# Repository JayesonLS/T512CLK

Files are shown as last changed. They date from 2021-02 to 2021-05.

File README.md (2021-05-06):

Schematics for the ATD T512CLK-A1 derived from Rob Krenicki's board layout
==========================================================================

There may be errors. That said, I found none in Rob Krenicki's work. KiCad's ERC and DRC checks likely caught all important errors in my work.

Do not produce the PCB layout from this KiCad project. Placing of standard KiCad parts onto the board has resulted in insufficient track spacing for production. If you wish to make a board, use Rob Krenicki's gerbers.

**Data point of note:** the required clock chip appears to be a DS1216B or DS1216C. I have tested a DS1216C successfully. I believe either variant will work given that no chip will be fitted into the DS1216. Note that this clock chip is not the more typical DS1216E SmartWatch chip for which there are reproductions. I have designed a replacement here: https://github.com/JayesonLS/SmartWatchRedux . Alternatively, used DS1216B or DS1216C's are still readily available from eBay, etc. They likely have dead batteries and an external replacement battery can be retrofitted with some work. Google "DS1216 battery replacement".

Software for the ATD-20 (or DS1216-C) clock fitted to a T512CLK-A1 is available from here: http://www.minuszerodegrees.net/rtc/rtc.htm . This software seems to correctly support current dates.

More information on the T512CLK is available from Rob Krenicki's project: https://github.com/rkrenicki/Tandy1000-DMA-Upgrade

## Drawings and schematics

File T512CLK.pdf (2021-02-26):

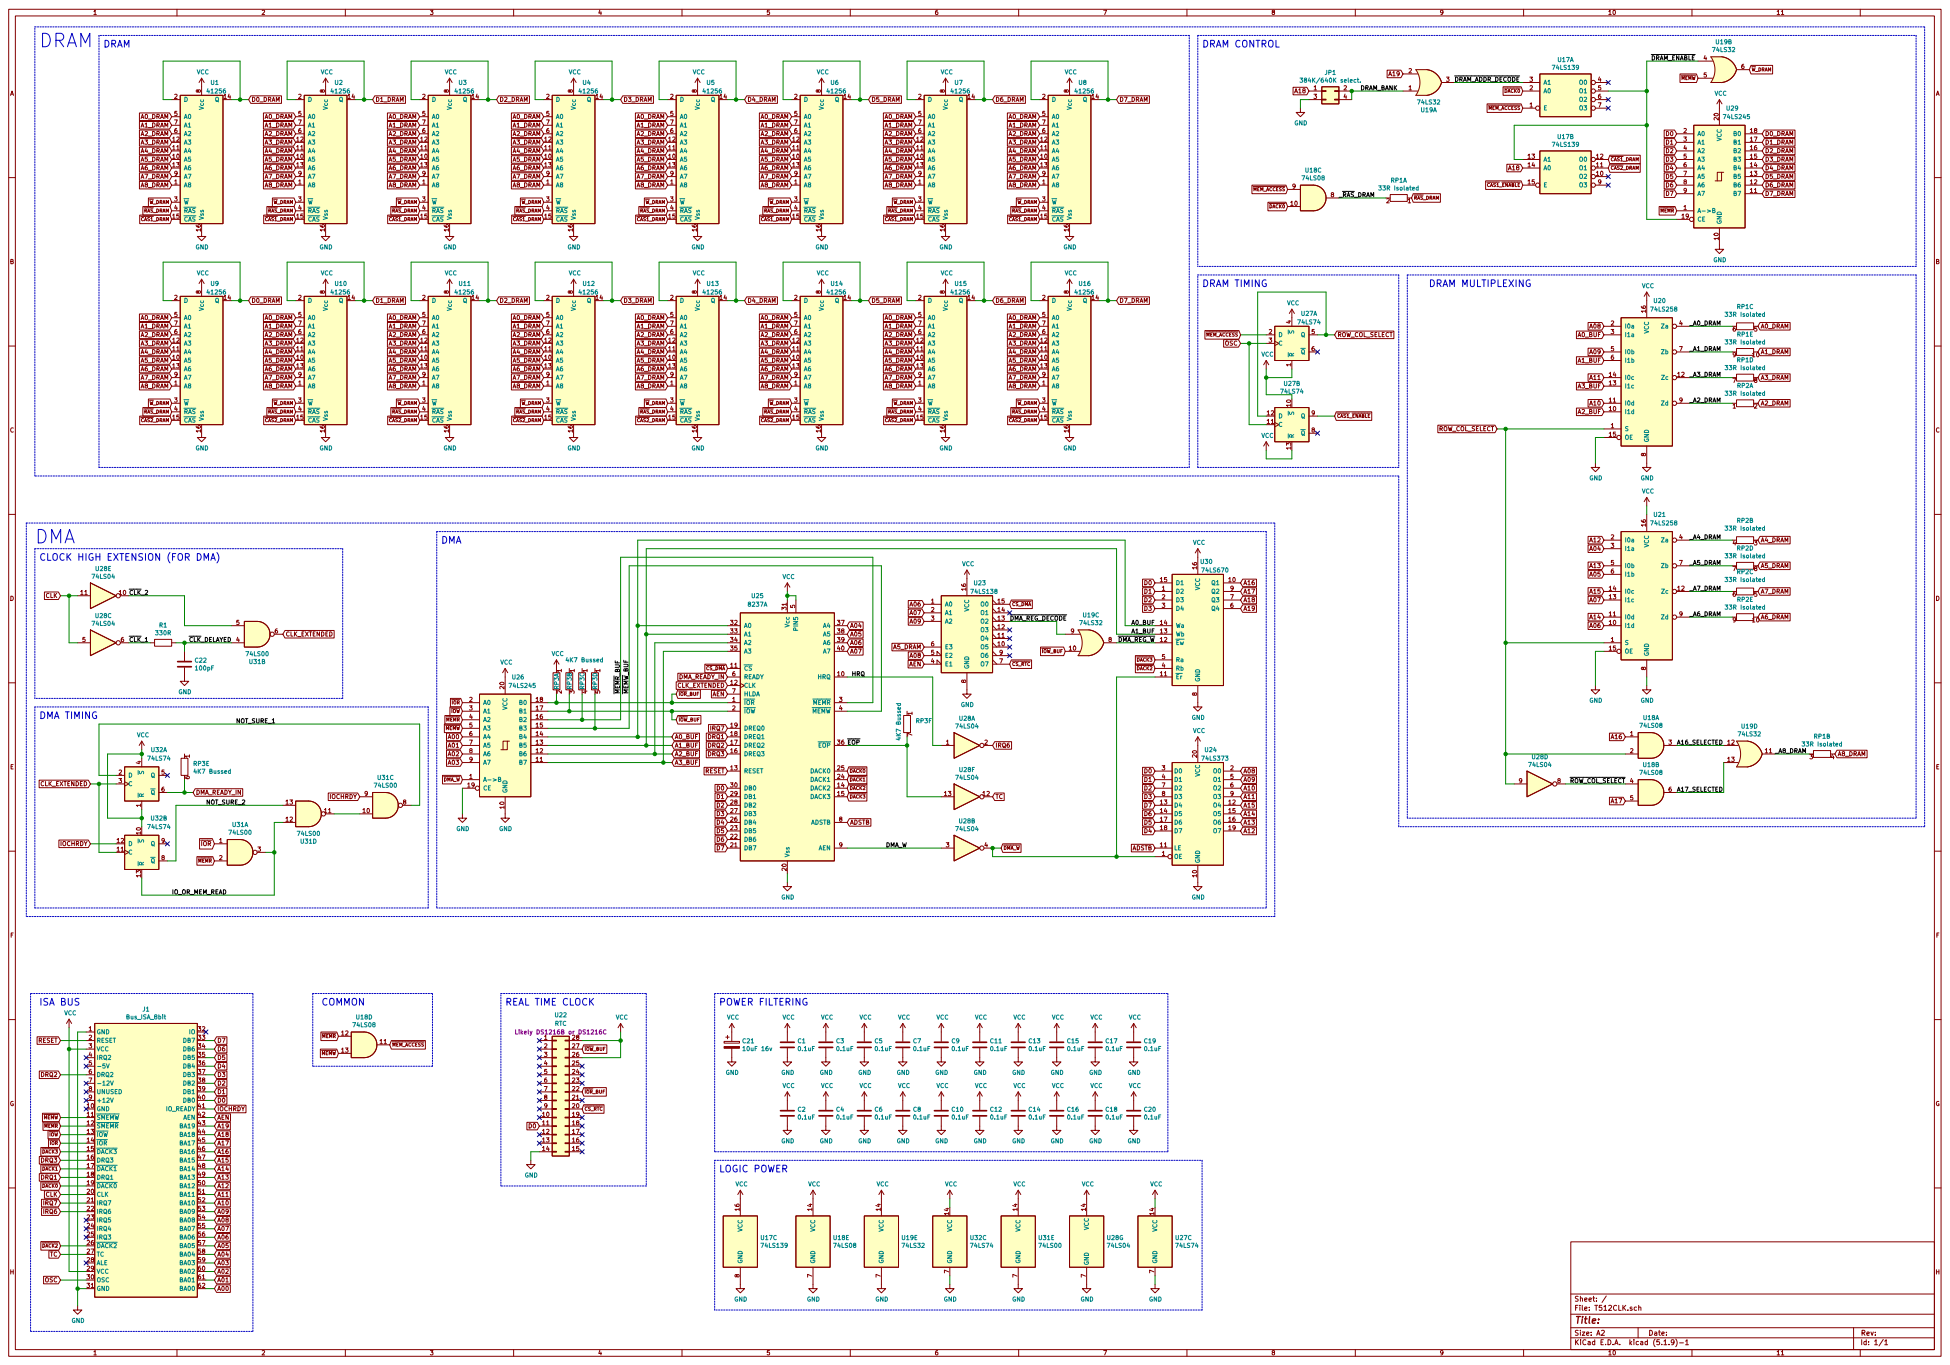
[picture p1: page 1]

CLOCK HIGH EXTENSION (FOR DMA)

5 READY 6 HLDA 7 ADSTB 8 AEN 9 U25

0.1uF GND
Id: 1/1 Title: File: T512CLK.sch Sheet: / VCC

74LS32 VCC GND VCC 14 GND

74LS74 VCC GND VCC 14 GND

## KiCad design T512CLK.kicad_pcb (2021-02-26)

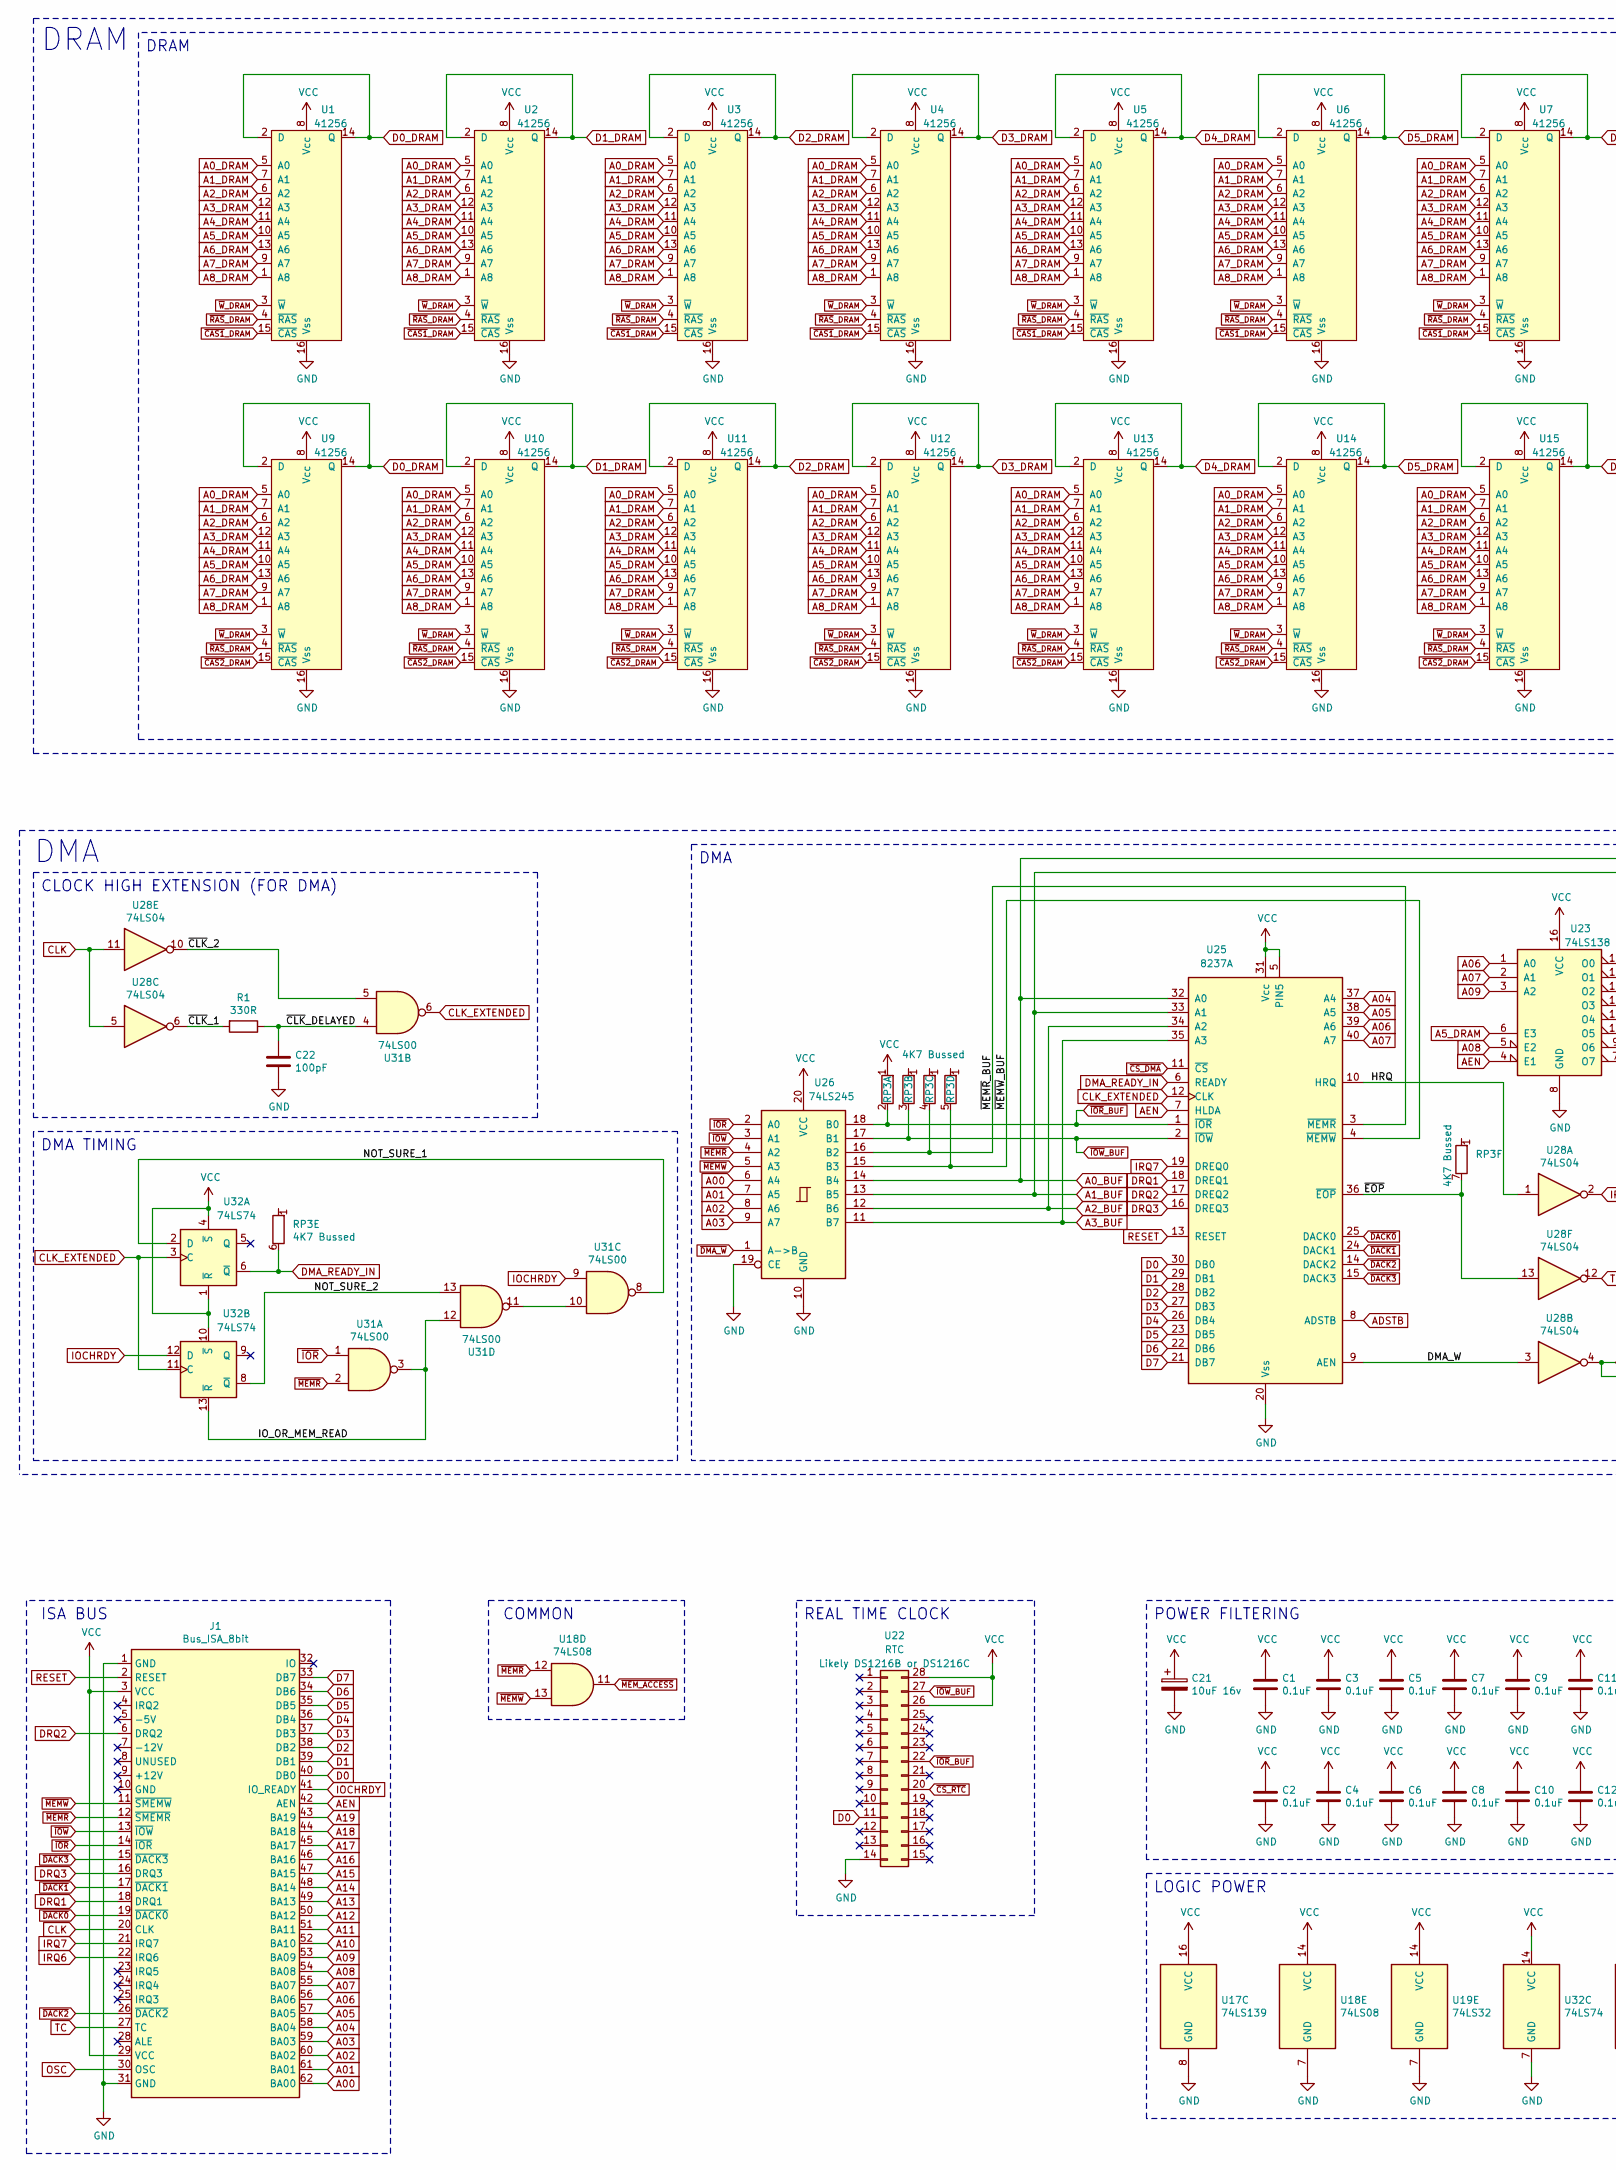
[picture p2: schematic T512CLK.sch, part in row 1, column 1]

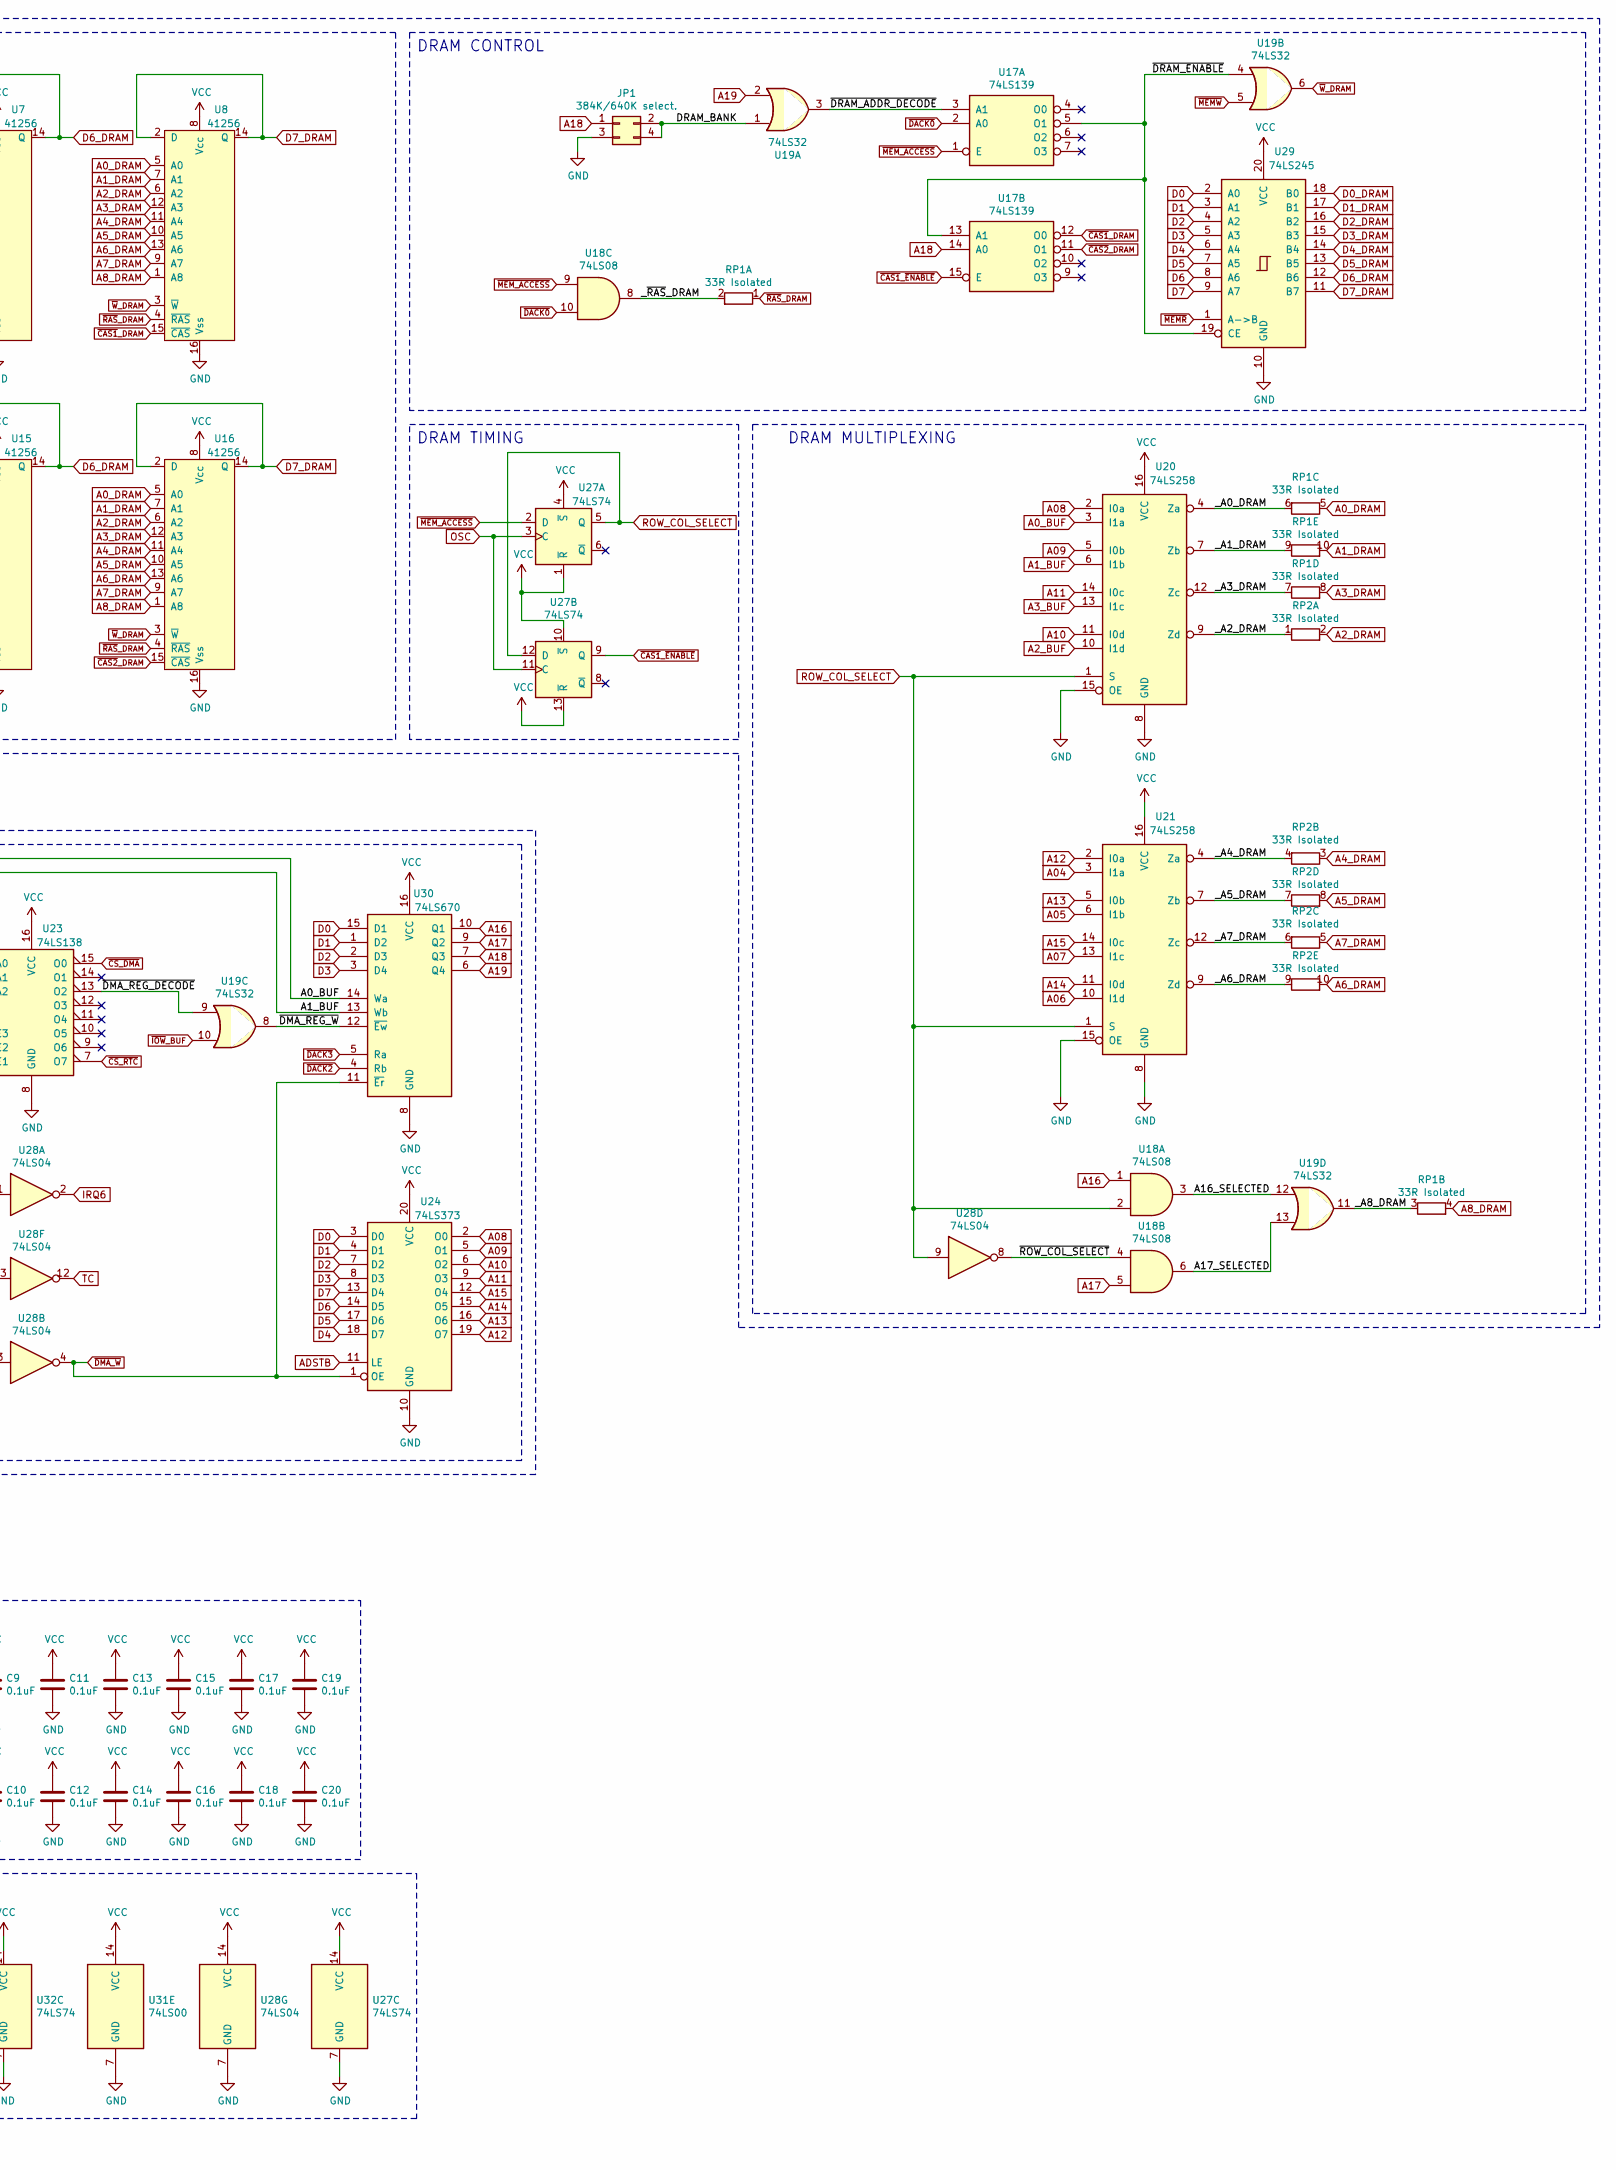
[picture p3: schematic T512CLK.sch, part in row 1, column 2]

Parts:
C1, C2, C3, C4, C5, C6, C7, C8, C9, C10, C11, C12, C13, C14, C15, C16, C17, C18, C19, C20: 0.1uF; C_Ceramic
C21: 10uF 16v; CP_Radial_Tantal_D5.0mm_P2.50mm
C22: 100pF; C_Ceramic
J1: Bus_ISA_8bit; BUS_AT
JP1: 384K/640K select.; PinHeader_2x02_P2.54mm_Vertical
R1: 330R; R_Axial_DIN0309_L9.0mm_D3.2mm_P12.70mm_Horizontal
RP1, RP2: 33R Isolated; R_Array_SIP10
RP3: 4K7 Bussed; R_Array_SIP8
U1, U2, U3, U4, U5, U6, U7, U8, U9, U10, U11, U12, U13, U14, U15, U16: 41256; DIP-16_W7.62mm
U17: 74LS139; DIP-16_W7.62mm
U18: 74LS08; DIP-14_W7.62mm
U19: 74LS32; DIP-14_W7.62mm
U20, U21: 74LS258; DIP-16_W7.62mm
U22: RTC; DIP-28_W15.24mm
U23: 74LS138; DIP-16_W7.62mm
U24: 74LS373; DIP-20_W7.62mm
U25: 8237A; DIP-40_W15.24mm
U26, U29: 74LS245; DIP-20_W7.62mm
U27, U32: 74LS74; DIP-14_W7.62mm
U28: 74LS04; DIP-14_W7.62mm
U30: 74LS670; DIP-16_W7.62mm
U31: 74LS00; DIP-14_W7.62mm

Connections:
/A16_SELECTED: U18.3, U19.12
/A17_SELECTED: U18.6, U19.13
/DMA_W: U25.9 (AEN), U28.3
/DRAM_BANK: JP1.2, JP1.4, U19.1
/HRQ: U25.10 (HRQ), U28.1
/IO_OR_MEM_READ: U31.3, U31.12, U32.13 (~R)
/NOT_SURE_1: U31.8, U32.2 (D)
/NOT_SURE_2: U31.13, U32.8 (~Q)
/_A0_DRAM: RP1.6 (R3.2), U20.4 (Za)
/_A1_DRAM: RP1.9 (R5.1), U20.7 (Zb)
/_A2_DRAM: RP2.1 (R1.1), U20.9 (Zd)
/_A3_DRAM: RP1.7 (R4.1), U20.12 (Zc)
/_A4_DRAM: RP2.4 (R2.2), U21.4 (Za)
/_A5_DRAM: RP2.7 (R4.1), U21.7 (Zb)
/_A6_DRAM: RP2.9 (R5.1), U21.9 (Zd)
/_A7_DRAM: RP2.6 (R3.2), U21.12 (Zc)
/_A8_DRAM: RP1.3 (R2.1), U19.11
/_~RAS~_DRAM: RP1.2 (R1.2), U18.8
/~CLK~_1: R1.2, U28.6
/~CLK~_2: U28.10, U31.5
/~CLK~_DELAYED: C22.1, R1.1, U31.4
/~DMA_REG_DECODE: U19.9, U23.13 (O2)
/~DMA_REG_W: U19.8, U30.12 (~Ew)
/~DRAM_ADDR_DECODE: U17.3 (A1), U19.3
/~DRAM_ENABLE: U17.5 (O1), U17.13 (A1), U19.4, U29.19 (CE)
/~EOP: RP3.7 (R6.2), U25.36 (~EOP~), U28.13
/~MEMR~_BUF: RP3.4 (R3.2), U25.3 (~MEMR~), U26.16 (B2)
/~MEMW~_BUF: RP3.5 (R4.2), U25.4 (~MEMW~), U26.15 (B3)
/~ROW_COL_SELECT: U18.4, U28.8
A00: J1.62 (BA00), U26.6 (A4)
A0_BUF: U20.3 (I1a), U25.32 (A0), U26.14 (B4), U30.14 (Wa)
A0_DRAM: RP1.5 (R3.1), U1.5 (A0), U2.5 (A0), U3.5 (A0), U4.5 (A0), U5.5 (A0), U6.5 (A0), U7.5 (A0), U8.5 (A0), U9.5 (A0), U10.5 (A0), U11.5 (A0), U12.5 (A0), U13.5 (A0), U14.5 (A0), U15.5 (A0), U16.5 (A0)
A01: J1.61 (BA01), U26.7 (A5)
A1_BUF: U20.6 (I1b), U25.33 (A1), U26.13 (B5), U30.13 (Wb)
A1_DRAM: RP1.10 (R5.2), U1.7 (A1), U2.7 (A1), U3.7 (A1), U4.7 (A1), U5.7 (A1), U6.7 (A1), U7.7 (A1), U8.7 (A1), U9.7 (A1), U10.7 (A1), U11.7 (A1), U12.7 (A1), U13.7 (A1), U14.7 (A1), U15.7 (A1), U16.7 (A1)
A02: J1.60 (BA02), U26.8 (A6)
A2_BUF: U20.10 (I1d), U25.34 (A2), U26.12 (B6)
A2_DRAM: RP2.2 (R1.2), U1.6 (A2), U2.6 (A2), U3.6 (A2), U4.6 (A2), U5.6 (A2), U6.6 (A2), U7.6 (A2), U8.6 (A2), U9.6 (A2), U10.6 (A2), U11.6 (A2), U12.6 (A2), U13.6 (A2), U14.6 (A2), U15.6 (A2), U16.6 (A2)
A03: J1.59 (BA03), U26.9 (A7)
A3_BUF: U20.13 (I1c), U25.35 (A3), U26.11 (B7)
A3_DRAM: RP1.8 (R4.2), U1.12 (A3), U2.12 (A3), U3.12 (A3), U4.12 (A3), U5.12 (A3), U6.12 (A3), U7.12 (A3), U8.12 (A3), U9.12 (A3), U10.12 (A3), U11.12 (A3), U12.12 (A3), U13.12 (A3), U14.12 (A3), U15.12 (A3), U16.12 (A3)
A04: J1.58 (BA04), U21.3 (I1a), U25.37 (A4)
A4_DRAM: RP2.3 (R2.1), U1.11 (A4), U2.11 (A4), U3.11 (A4), U4.11 (A4), U5.11 (A4), U6.11 (A4), U7.11 (A4), U8.11 (A4), U9.11 (A4), U10.11 (A4), U11.11 (A4), U12.11 (A4), U13.11 (A4), U14.11 (A4), U15.11 (A4), U16.11 (A4)
A05: J1.57 (BA05), U21.6 (I1b), U25.38 (A5)
A5_DRAM: RP2.8 (R4.2), U1.10 (A5), U2.10 (A5), U3.10 (A5), U4.10 (A5), U5.10 (A5), U6.10 (A5), U7.10 (A5), U8.10 (A5), U9.10 (A5), U10.10 (A5), U11.10 (A5), U12.10 (A5), U13.10 (A5), U14.10 (A5), U15.10 (A5), U16.10 (A5), U23.6 (E3)
A06: J1.56 (BA06), U21.10 (I1d), U23.1 (A0), U25.39 (A6)
A6_DRAM: RP2.10 (R5.2), U1.13 (A6), U2.13 (A6), U3.13 (A6), U4.13 (A6), U5.13 (A6), U6.13 (A6), U7.13 (A6), U8.13 (A6), U9.13 (A6), U10.13 (A6), U11.13 (A6), U12.13 (A6), U13.13 (A6), U14.13 (A6), U15.13 (A6), U16.13 (A6)
A07: J1.55 (BA07), U21.13 (I1c), U23.2 (A1), U25.40 (A7)
A7_DRAM: RP2.5 (R3.1), U1.9 (A7), U2.9 (A7), U3.9 (A7), U4.9 (A7), U5.9 (A7), U6.9 (A7), U7.9 (A7), U8.9 (A7), U9.9 (A7), U10.9 (A7), U11.9 (A7), U12.9 (A7), U13.9 (A7), U14.9 (A7), U15.9 (A7), U16.9 (A7)
A08: J1.54 (BA08), U20.2 (I0a), U23.5 (E2), U24.2 (O0)
A8_DRAM: RP1.4 (R2.2), U1.1 (A8), U2.1 (A8), U3.1 (A8), U4.1 (A8), U5.1 (A8), U6.1 (A8), U7.1 (A8), U8.1 (A8), U9.1 (A8), U10.1 (A8), U11.1 (A8), U12.1 (A8), U13.1 (A8), U14.1 (A8), U15.1 (A8), U16.1 (A8)
A09: J1.53 (BA09), U20.5 (I0b), U23.3 (A2), U24.5 (O1)
A10: J1.52 (BA10), U20.11 (I0d), U24.6 (O2)
A11: J1.51 (BA11), U20.14 (I0c), U24.9 (O3)
A12: J1.50 (BA12), U21.2 (I0a), U24.19 (O7)
A13: J1.49 (BA13), U21.5 (I0b), U24.16 (O6)
A14: J1.48 (BA14), U21.11 (I0d), U24.15 (O5)
A15: J1.47 (BA15), U21.14 (I0c), U24.12 (O4)
A16: J1.46 (BA16), U18.1, U30.10 (Q1)
A17: J1.45 (BA17), U18.5, U30.9 (Q2)
A18: J1.44 (BA18), JP1.1, U17.14 (A0), U30.7 (Q3)
A19: J1.43 (BA19), U19.2, U30.6 (Q4)
ADSTB: U24.11 (LE), U25.8 (ADSTB)
AEN: J1.42 (AEN), U23.4 (E1), U25.7 (HLDA)
CLK: J1.20 (CLK), U28.5, U28.11
CLK_EXTENDED: U25.12 (CLK), U31.6, U32.3 (C), U32.11 (C)
D0: J1.40 (DB0), U22.11, U24.3 (D0), U25.30 (DB0), U29.2 (A0), U30.15 (D1)
D0_DRAM: U1.2 (D), U1.14 (Q), U9.2 (D), U9.14 (Q), U29.18 (B0)
D1: J1.39 (DB1), U24.4 (D1), U25.29 (DB1), U29.3 (A1), U30.1 (D2)
D1_DRAM: U2.2 (D), U2.14 (Q), U10.2 (D), U10.14 (Q), U29.17 (B1)
D2: J1.38 (DB2), U24.7 (D2), U25.28 (DB2), U29.4 (A2), U30.2 (D3)
D2_DRAM: U3.2 (D), U3.14 (Q), U11.2 (D), U11.14 (Q), U29.16 (B2)
D3: J1.37 (DB3), U24.8 (D3), U25.27 (DB3), U29.5 (A3), U30.3 (D4)
D3_DRAM: U4.2 (D), U4.14 (Q), U12.2 (D), U12.14 (Q), U29.15 (B3)
D4: J1.36 (DB4), U24.18 (D7), U25.26 (DB4), U29.6 (A4)
D4_DRAM: U5.2 (D), U5.14 (Q), U13.2 (D), U13.14 (Q), U29.14 (B4)
D5: J1.35 (DB5), U24.17 (D6), U25.23 (DB5), U29.7 (A5)
D5_DRAM: U6.2 (D), U6.14 (Q), U14.2 (D), U14.14 (Q), U29.13 (B5)
D6: J1.34 (DB6), U24.14 (D5), U25.22 (DB6), U29.8 (A6)
D6_DRAM: U7.2 (D), U7.14 (Q), U15.2 (D), U15.14 (Q), U29.12 (B6)
D7: J1.33 (DB7), U24.13 (D4), U25.21 (DB7), U29.9 (A7)
D7_DRAM: U8.2 (D), U8.14 (Q), U16.2 (D), U16.14 (Q), U29.11 (B7)
DMA_READY_IN: RP3.6 (R5.2), U25.6 (READY), U32.6 (~Q)
DRQ1: J1.18 (DRQ1), U25.18 (DREQ1)
DRQ2: J1.6 (DRQ2), U25.17 (DREQ2)
DRQ3: J1.16 (DRQ3), U25.16 (DREQ3)
GND: C1.2, C2.2, C3.2, C4.2, C5.2, C6.2, C7.2, C8.2, C9.2, C10.2, C11.2, C12.2, C13.2, C14.2, C15.2, C16.2, C17.2, C18.2, C19.2, C20.2, C21.2, C22.2, J1.1 (GND), J1.31 (GND), JP1.3, U1.16 (Vss), U2.16 (Vss), U3.16 (Vss), U4.16 (Vss), U5.16 (Vss), U6.16 (Vss), U7.16 (Vss), U8.16 (Vss), U9.16 (Vss), U10.16 (Vss), U11.16 (Vss), U12.16 (Vss), U13.16 (Vss), U14.16 (Vss), U15.16 (Vss), U16.16 (Vss), U17.8 (GND), U18.7 (GND), U19.7 (GND), U20.8 (GND), U20.15 (OE), U21.8 (GND), U21.15 (OE), U22.14, U23.8 (GND), U24.10 (GND), U25.20 (Vss), U26.10 (GND), U26.19 (CE), U27.7 (GND), U28.7 (GND), U29.10 (GND), U30.8 (GND), U31.7 (GND), U32.7 (GND)
IOCHRDY: J1.41 (IO_READY), U31.9, U32.12 (D)
IRQ6: J1.22 (IRQ6), U28.2
IRQ7: J1.21 (IRQ7), U25.19 (DREQ0)
unnamed: U31.10, U31.11
OSC: J1.30 (OSC), U27.3 (C), U27.11 (C)
RESET: J1.2 (RESET), U25.13 (RESET)
ROW_COL_SELECT: U18.2, U20.1 (S), U21.1 (S), U27.5 (Q), U27.12 (D), U28.9
TC: J1.27 (TC), U28.12
VCC: C1.1, C2.1, C3.1, C4.1, C5.1, C6.1, C7.1, C8.1, C9.1, C10.1, C11.1, C12.1, C13.1, C14.1, C15.1, C16.1, C17.1, C18.1, C19.1, C20.1, C21.1, J1.3 (VCC), J1.29 (VCC), RP3.1 (R1.1), U1.8 (Vcc), U2.8 (Vcc), U3.8 (Vcc), U4.8 (Vcc), U5.8 (Vcc), U6.8 (Vcc), U7.8 (Vcc), U8.8 (Vcc), U9.8 (Vcc), U10.8 (Vcc), U11.8 (Vcc), U12.8 (Vcc), U13.8 (Vcc), U14.8 (Vcc), U15.8 (Vcc), U16.8 (Vcc), U17.16 (VCC), U18.14 (VCC), U19.14 (VCC), U20.16 (VCC), U21.16 (VCC), U22.26, U22.28, U23.16 (VCC), U24.20 (VCC), U25.5 (PIN5), U25.31 (Vcc), U26.20 (VCC), U27.1 (~R), U27.4 (~S), U27.10 (~S), U27.13 (~R), U27.14 (VCC), U28.14 (VCC), U29.20 (VCC), U30.16 (VCC), U31.14 (VCC), U32.1 (~R), U32.4 (~S), U32.10 (~S), U32.14 (VCC)
~CAS1~_DRAM: U1.15 (~CAS), U2.15 (~CAS), U3.15 (~CAS), U4.15 (~CAS), U5.15 (~CAS), U6.15 (~CAS), U7.15 (~CAS), U8.15 (~CAS), U17.12 (O0)
~CAS1~_~ENABLE: U17.15 (E), U27.9 (Q)
~CAS2~_DRAM: U9.15 (~CAS), U10.15 (~CAS), U11.15 (~CAS), U12.15 (~CAS), U13.15 (~CAS), U14.15 (~CAS), U15.15 (~CAS), U16.15 (~CAS), U17.11 (O1)
~CS_DMA: U23.15 (O0), U25.11 (~CS~)
~CS_RTC: U22.20, U23.7 (O7)
~DACK0: J1.19 (~DACK0), U17.2 (A0), U18.10, U25.25 (DACK0)
~DACK1: J1.17 (~DACK1), U25.24 (DACK1)
~DACK2: J1.26 (~DACK2), U25.14 (DACK2), U30.4 (Rb)
~DACK3: J1.15 (~DACK3), U25.15 (DACK3), U30.5 (Ra)
~DMA_W: U24.1 (OE), U26.1 (A->B), U28.4, U30.11 (~Er)
~IOR: J1.14 (~IOR), U26.2 (A0), U31.1
~IOR~_BUF: RP3.2 (R1.2), U22.22, U25.1 (~IOR~), U26.18 (B0)
~IOW: J1.13 (~IOW), U26.3 (A1)
~IOW~_BUF: RP3.3 (R2.2), U19.10, U22.27, U25.2 (~IOW~), U26.17 (B1)
~MEMR: J1.12 (~SMEMR), U18.12, U26.4 (A2), U29.1 (A->B), U31.2
~MEMW: J1.11 (~SMEMW), U18.13, U19.5, U26.5 (A3)
~MEM_ACCESS: U17.1 (E), U18.9, U18.11, U27.2 (D)
~RAS~_DRAM: RP1.1 (R1.1), U1.4 (~RAS), U2.4 (~RAS), U3.4 (~RAS), U4.4 (~RAS), U5.4 (~RAS), U6.4 (~RAS), U7.4 (~RAS), U8.4 (~RAS), U9.4 (~RAS), U10.4 (~RAS), U11.4 (~RAS), U12.4 (~RAS), U13.4 (~RAS), U14.4 (~RAS), U15.4 (~RAS), U16.4 (~RAS)
~W~_DRAM: U1.3 (~W), U2.3 (~W), U3.3 (~W), U4.3 (~W), U5.3 (~W), U6.3 (~W), U7.3 (~W), U8.3 (~W), U9.3 (~W), U10.3 (~W), U11.3 (~W), U12.3 (~W), U13.3 (~W), U14.3 (~W), U15.3 (~W), U16.3 (~W), U19.6

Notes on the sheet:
REAL TIME CLOCK
POWER FILTERING
LOGIC POWER
DRAM
ISA BUS
DMA TIMING
DMA
CLOCK HIGH EXTENSION (FOR DMA)
COMMON
DRAM CONTROL
DRAM MULTIPLEXING
DRAM TIMING

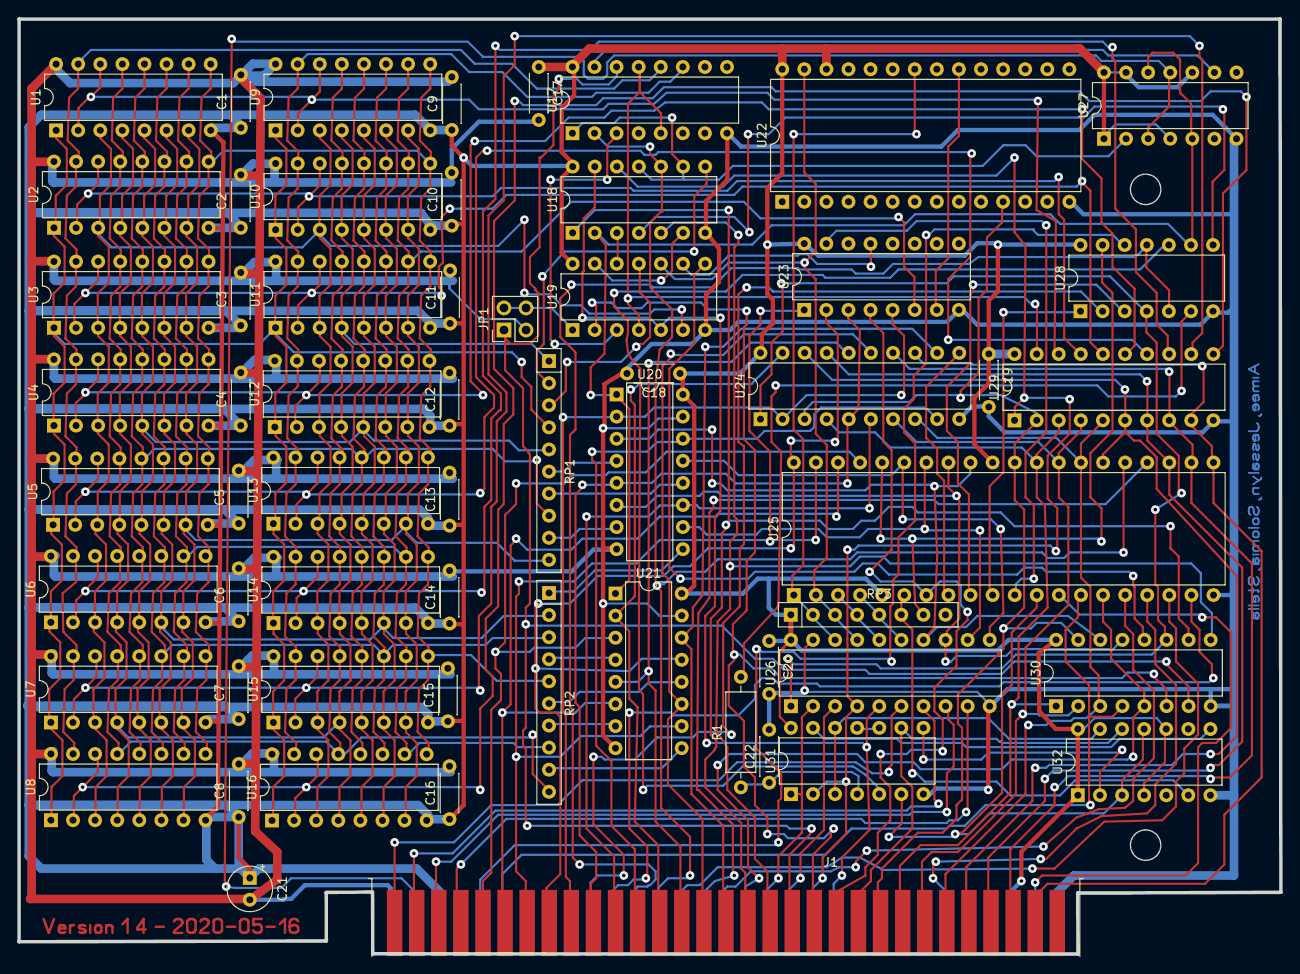
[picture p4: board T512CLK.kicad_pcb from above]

Board: 2 copper layers, 145.1 x 107.5 mm, 60 parts (0 on the bottom side), 115 nets.

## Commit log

2021-02-26 Add rkrenicki's Gerbers.
    [T512CLK-clone.DRL, T512CLK-clone_copper_bottom.gbr, T512CLK-clone_copper_top.gbr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]
2021-02-26 Add first complete pass of KiCad project.
    [T512CLK.kicad_pcb, T512CLK.sch]
2021-02-26 Change RP3 symbol from a single to split for better readability.
    [T512CLK.kicad_pcb, T512CLK.sch]
2021-02-26 Change RP1 and RP2 symbols from single to split for better readability.
    [T512CLK.kicad_pcb, T512CLK.sch]
2021-02-26 Update PDF schematic plot.
